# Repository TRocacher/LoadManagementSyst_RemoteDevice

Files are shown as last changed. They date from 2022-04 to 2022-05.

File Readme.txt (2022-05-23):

Branche DevRTC_StdBy_LL

-> Le développement HAL standby et RTC est un échec, le processeur est bricked car endormi à jamais...
nRST et VCC sont en CC sérieux. Voir de plus près.
-> Jusque là le code est vite lourd, 40% facile sans avoir trop rien fait...

Dans cette branche, on essaie de voir la conception en LL pour diminuer le code

Le répertoire de travail est /ExploreCodeStdby/MyNucleoL476_StdByPower

On crée un répertoire à partir de cube, en conception LL.
On va chercher l'exemple LL :
C:\Users\trocache\STM32Cube\Repository\STM32Cube_FW_L4_V1.17.2\Projects\NUCLEO-L476RG\Examples_LL\PWR\PWR_EnterStandbyMode

On récupère les 3 src et les 3 inc, que l'on copie dans le projet juste créé (remplacement de ceux créés par cube).
Compilation OK
SRC :
main.c 
stm32l4xx_it.c
system_stm32l4xx.c (est le même)

INC
main.h
stm32_assert.h
stm32l4xx_it.h

OBJ 1 : on fait idem mais périodique avec le wakeup timer.
OBJ 2 : faire tourner l'I2C en LL.

****************************
50abc65 
OBJ 1 en cours, bac à sable ajouté pour récupérer des codes générés automatiquement Cube.
/MyNucleoL476_StdByPower modifié, inspiré de RTC_ExitStandbyWithWakeUpTimer
A faire : Bien lire et faire une synthèse sur wakeup RTC Standby

****************************
349ff09
/ExploreCodeStdby / BacASable_LLFromCube
				  / MyNucleoL476_StdByPower
Programme opérationnel en standby mode !
		* PWR reset : LED s'allume 5s
		* nRST : LED s'allume 2s
		* standby wake up : LED s'allume 200ms

****************************
35642cd		
/ExploreCodeStdby / Remote_L041_StdByPower

Même programme sur 32L041F6P7
Programme opérationnel en standby mode !
		* PWR reset : PA1 (LEDIR) on 6s
		* nRST : PA1 (LEDIR) on  3s
		* standby wake up : PA1 (LEDIR) on  1s
		
Le tout sur le proto n°1 fait pas José.

****************************
2902111    
/ExploreCodeStdby / Remote_L041_StdByPower

Le programme fais une émission en boucle UART via FSK. Fonctionne à 38400 Bds, test en réception avec la carte tecom 103 de 4IS.
OK.
A faire réception.

62a0048 
/ExploreCodeStdby / Remote_L041_StdByPower
Pgm en IT à 9600 Bds, émetteur = RT606 et PC via XCTU. 
Voir main.c pour l'explication fin.
A ce stade, RxCmde, TxCmde, CD, Tx, Rx testés.

****************************	
b0ee319 
/ExploreCodeStdby / Remote_L041_StdByPower
Validation User BP en IT front descendant.

****************************
Après b0ee319 
ATTENTION CHANGEMENT REP ICI : /ExploreCodeStdby / BacASable_L041
Validation ADC mais soucis sur l'alimentation. Parasite important rayonné et conduit (20mV 100k à 30k)
qui parasite complètement l'ADC...

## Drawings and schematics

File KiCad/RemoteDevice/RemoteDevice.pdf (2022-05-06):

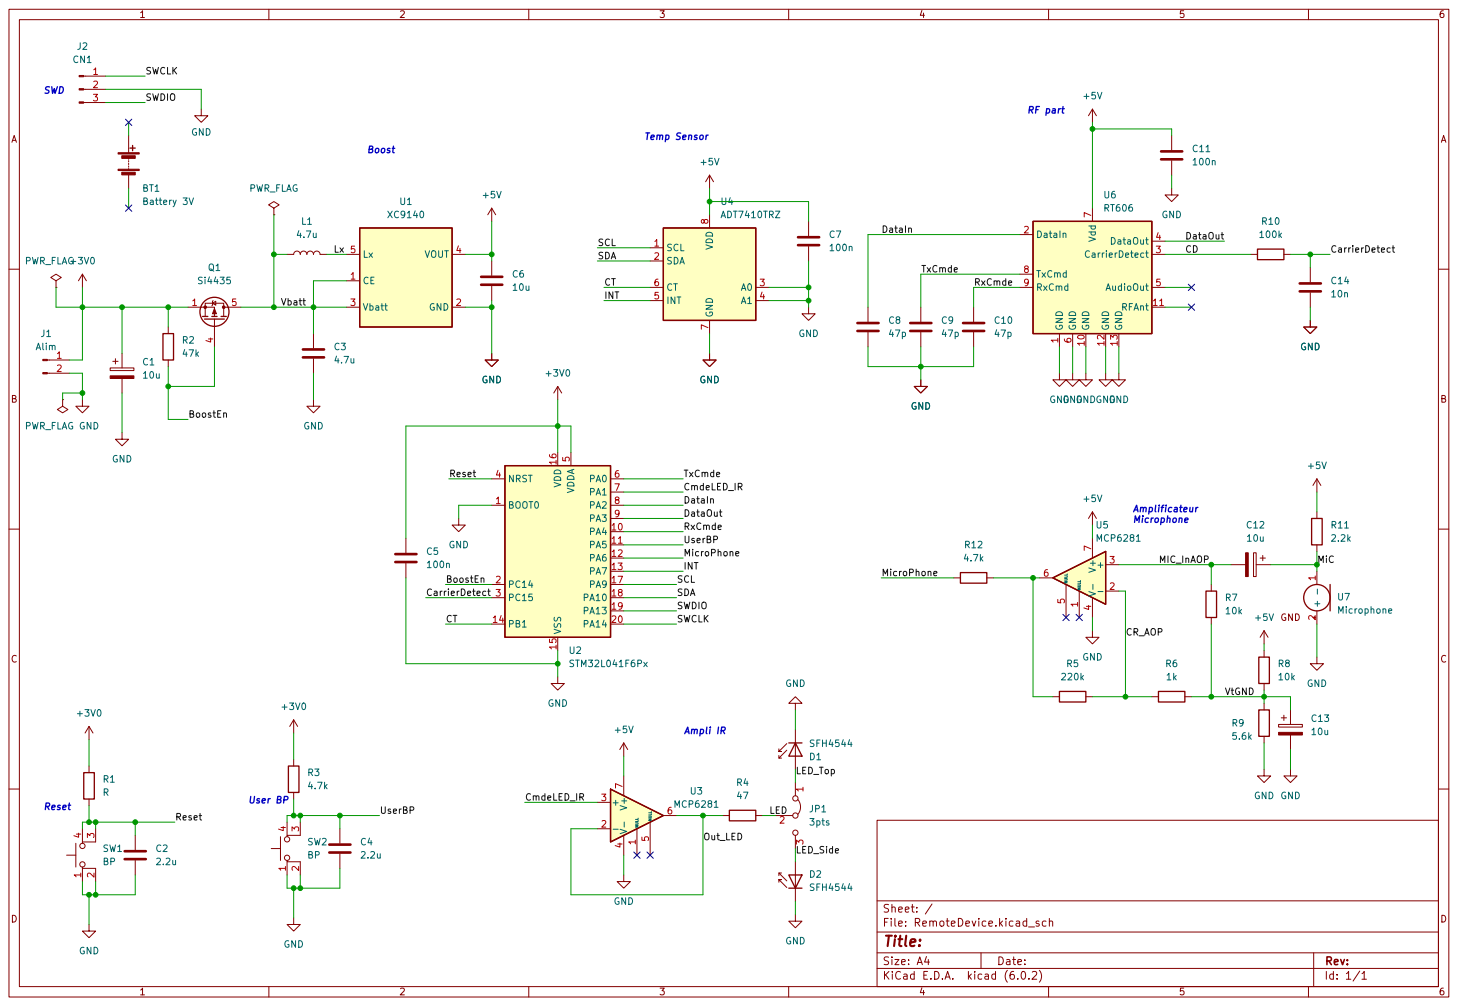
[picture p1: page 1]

1 GND 10 RFAnt 11 GND 12 GND 13 DataIn 2 CarrierDetect 3 DataOut 4 AudioOut 5 GND

File: RemoteDevice.kicad_sch Sheet: / GND

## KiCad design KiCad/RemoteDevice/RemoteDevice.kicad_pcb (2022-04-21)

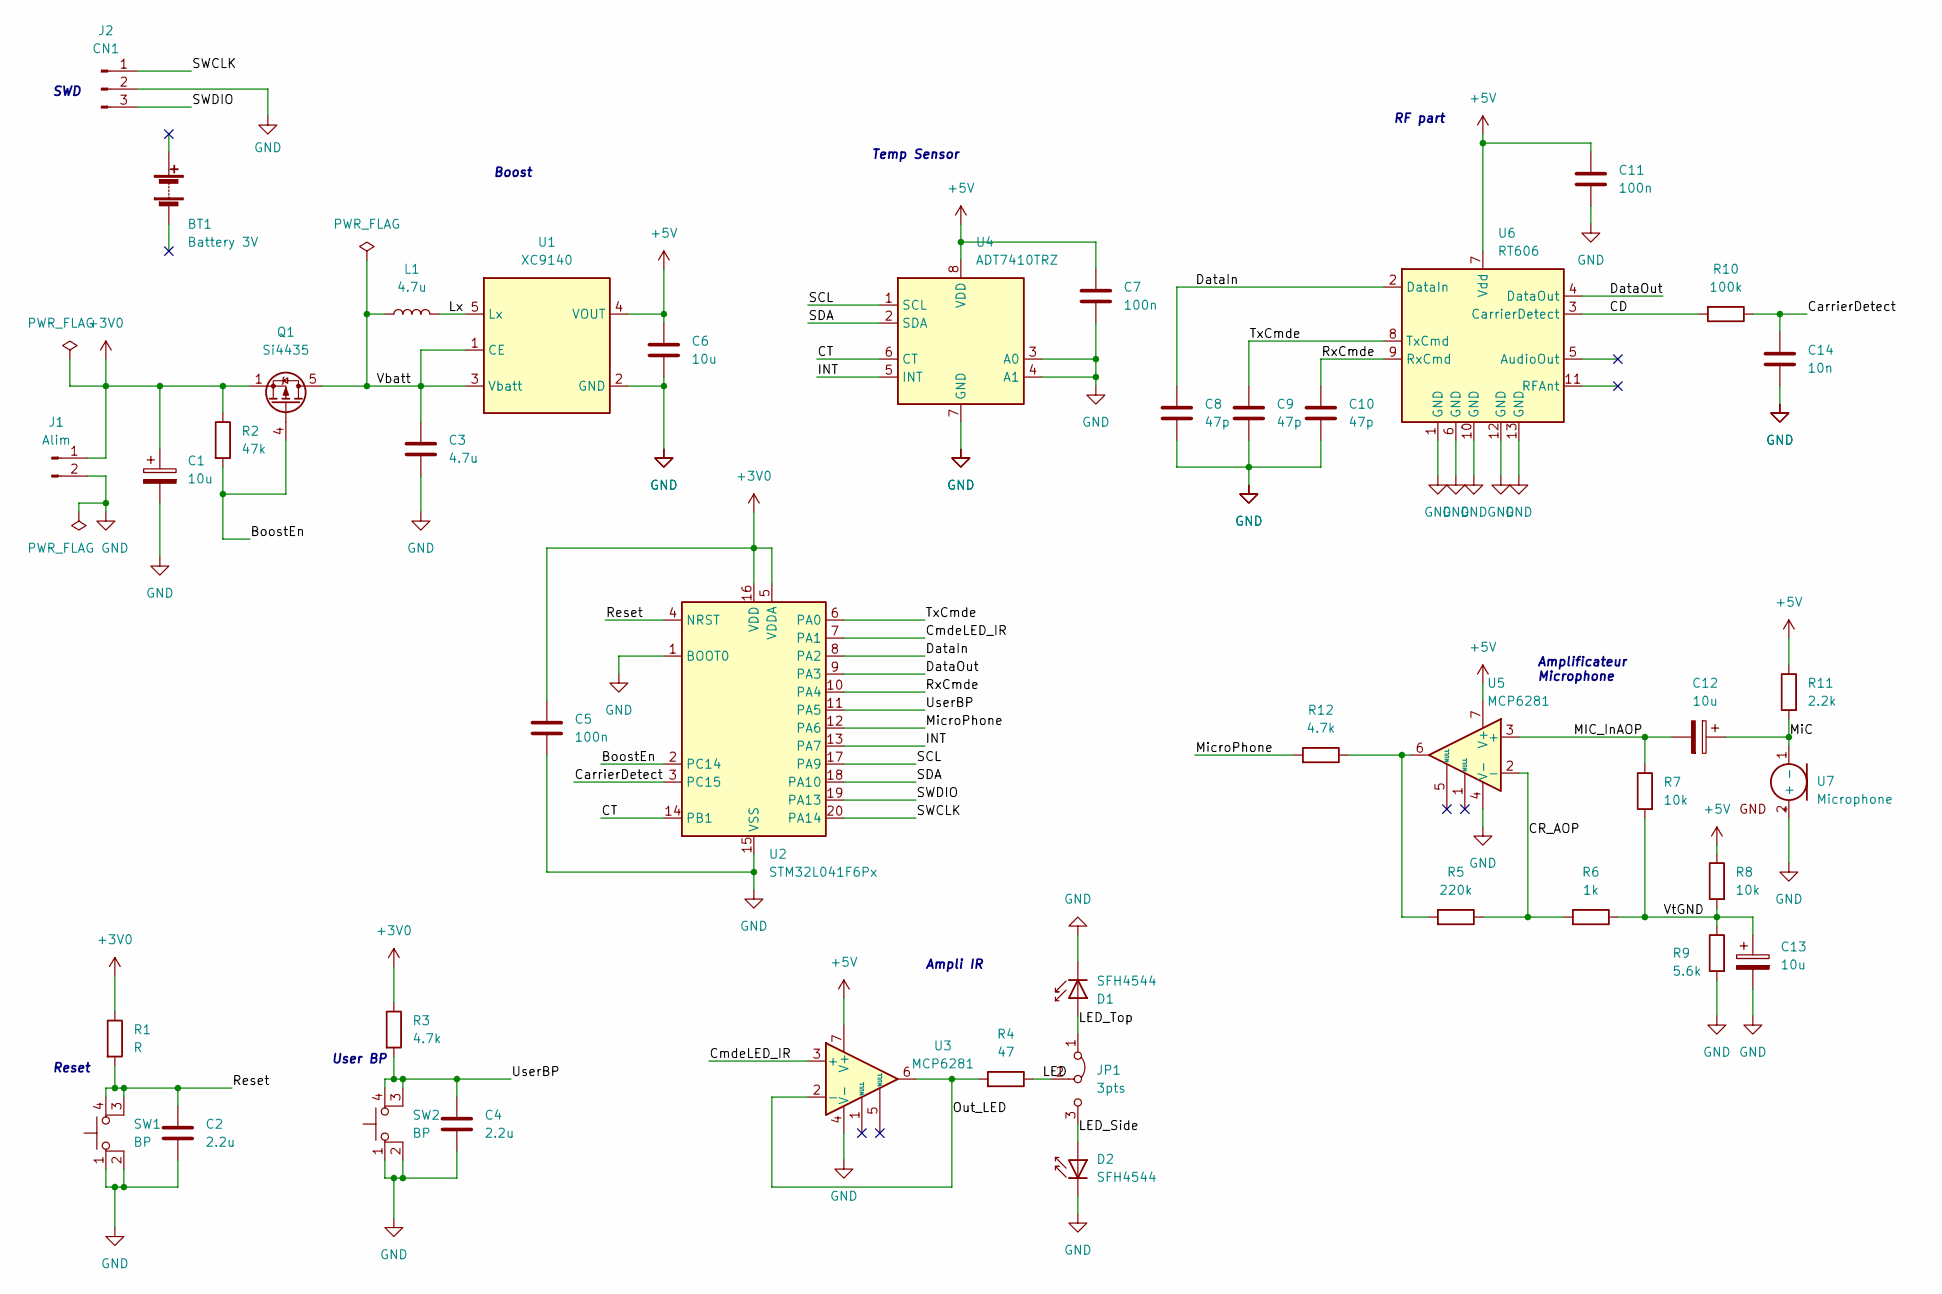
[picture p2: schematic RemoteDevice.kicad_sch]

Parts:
BT1: Battery 3V; BatteryHolder_Keystone_2468_2xAAA
C1, C12, C13: 10u; CP_EIA-7132-20_AVX-U
C2, C4: 2.2u; C_1812_4532Metric
C3: 4.7u; C_1812_4532Metric
C5, C7, C11: 100n; C_1206_3216Metric
C6: 10u; C_1812_4532Metric
C8, C9, C10: 47p; C_0805_2012Metric
C14: 10n; C_1206_3216Metric
D1, D2: SFH4544; LED_D5.0mm_IRGrey
J1: Alim; PinHeader2pts
J2: CN1; PinHeader3pts
JP1: 3pts; PinHeader3pts
L1: 4.7u; L_Abracon_ASPI-3012S
Q1: Si4435; PowerPAK_SO-8_Single
R1: R; R_1206_3216Metric
R2: 47k; R_1206_3216Metric
R3, R12: 4.7k; R_1206_3216Metric
R4: 47; R_1206_3216Metric
R5: 220k; R_1206_3216Metric
R6: 1k; R_1206_3216Metric
R7, R8: 10k; R_1206_3216Metric
R9: 5.6k; R_1206_3216Metric
R10: 100k; R_1206_3216Metric
R11: 2.2k; R_1206_3216Metric
SW1, SW2: BP; SW
U1: XC9140; SOT-23-5
U2: STM32L041F6Px; TSSOP-20_4.4x6.5mm_P0.65mm
U3, U5: MCP6281; SOIC-8_3.9x4.9mm_P1.27mm
U4: ADT7410TRZ; SOP-8_3.9x4.9mm_P1.27mm
U6: RT606
U7: Microphone

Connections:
+3V0: C1.1, C5.1, J1.1, Q1.1 (S), Q1.2 (S), Q1.3 (S), R1.1, R2.1, R3.1, U2.5 (VDDA), U2.16 (VDD)
+5V: C6.1, C7.1, C11.1, R8.1, R11.1, U1.4 (VOUT), U3.7 (V+), U4.8 (VDD), U5.7 (V+), U6.7 (Vdd)
/BoostEn: Q1.4 (G), R2.2, U2.2 (PC14)
/CD: R10.2, U6.3 (CarrierDetect)
/CR_AOP: R5.1, R6.2, U5.2 (-)
/CT: U2.14 (PB1), U4.6 (CT)
/CarrierDetect: C14.1, R10.1, U2.3 (PC15)
/CmdeLED_IR: U2.7 (PA1), U3.3 (+)
/DataIn: C8.1, U2.8 (PA2), U6.2 (DataIn)
/DataOut: U2.9 (PA3), U6.4 (DataOut)
/INT: U2.13 (PA7), U4.5 (INT)
/LED: JP1.2 (C), R4.1
/LED_Side: D2.2 (A), JP1.3 (B)
/LED_Top: D1.2 (A), JP1.1 (A)
/Lx: L1.1, U1.5 (Lx)
/MIC_InAOP: C12.2, R7.1, U5.3 (+)
/MiC: C12.1, R11.2, U7.1 (-)
/MicroPhone: R12.2, U2.12 (PA6)
/Out_LED: R4.2, U3.2 (-), U3.6
/Reset: C2.1, R1.2, SW1.3, SW1.4, U2.4 (NRST)
/RxCmde: C10.1, U2.10 (PA4), U6.9 (RxCmd)
/SCL: U2.17 (PA9), U4.1 (SCL)
/SDA: U2.18 (PA10), U4.2 (SDA)
/SWCLK: J2.1, U2.20 (PA14)
/SWDIO: J2.3, U2.19 (PA13)
/TxCmde: C9.1, U2.6 (PA0), U6.8 (TxCmd)
/UserBP: C4.1, R3.2, SW2.3, SW2.4, U2.11 (PA5)
/Vbatt: C3.1, L1.2, Q1.5 (D), U1.1 (CE), U1.3 (Vbatt)
/VtGND: C13.1, R6.1, R7.2, R8.2, R9.1
GND: C1.2, C2.2, C3.2, C4.2, C5.2, C6.2, C7.2, C8.2, C9.2, C10.2, C11.2, C13.2, C14.2, D1.1 (K), D2.1 (K), J1.2, J2.2, R9.2, SW1.1, SW1.2, SW2.1, SW2.2, U1.2 (GND), U2.1 (BOOT0), U2.15 (VSS), U3.4 (V-), U4.3 (A0), U4.4 (A1), U4.7 (GND), U5.4 (V-), U6.1 (GND), U6.6 (GND), U6.10 (GND), U6.12 (GND), U6.13 (GND), U7.2 (+)
unnamed: R5.2, R12.1, U5.6

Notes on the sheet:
Ampli IR
Boost
Reset
RF part
Amplificateur Microphone
Temp Sensor
User BP
SWD

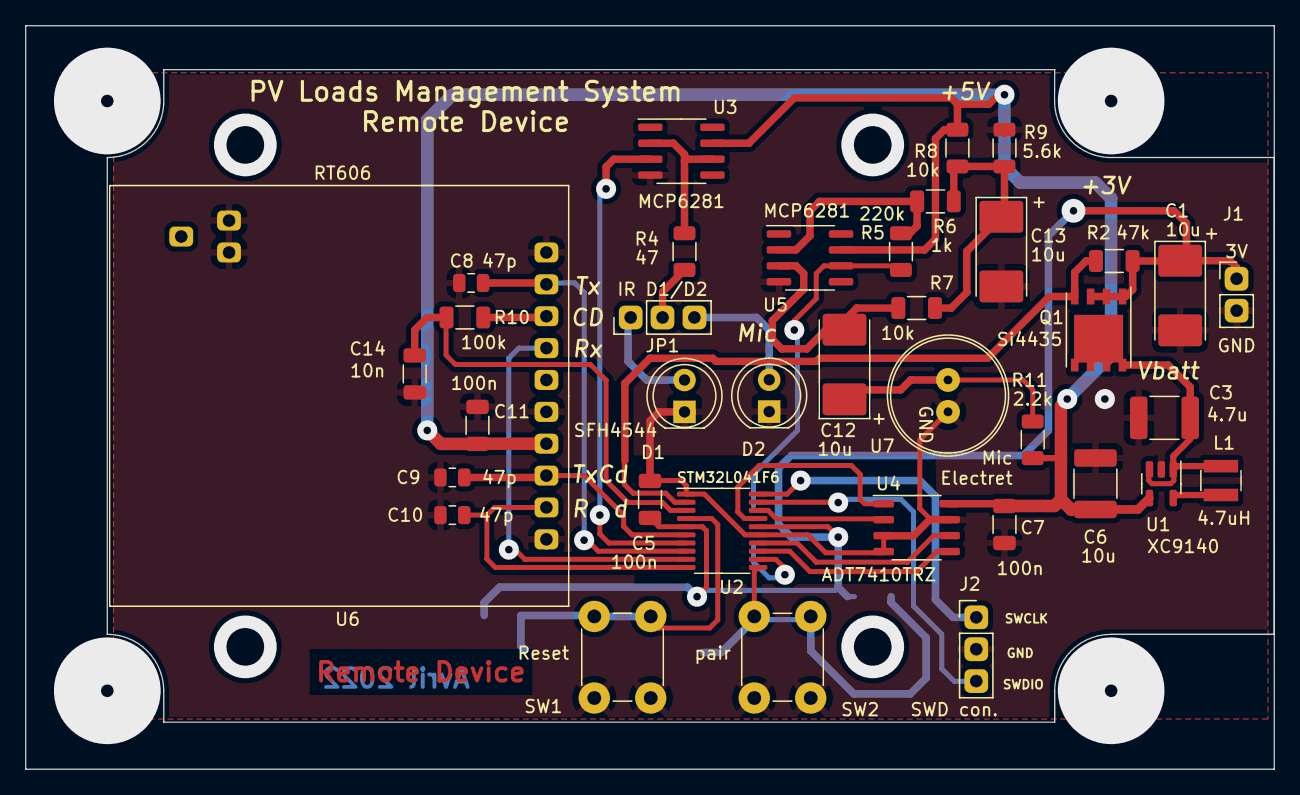
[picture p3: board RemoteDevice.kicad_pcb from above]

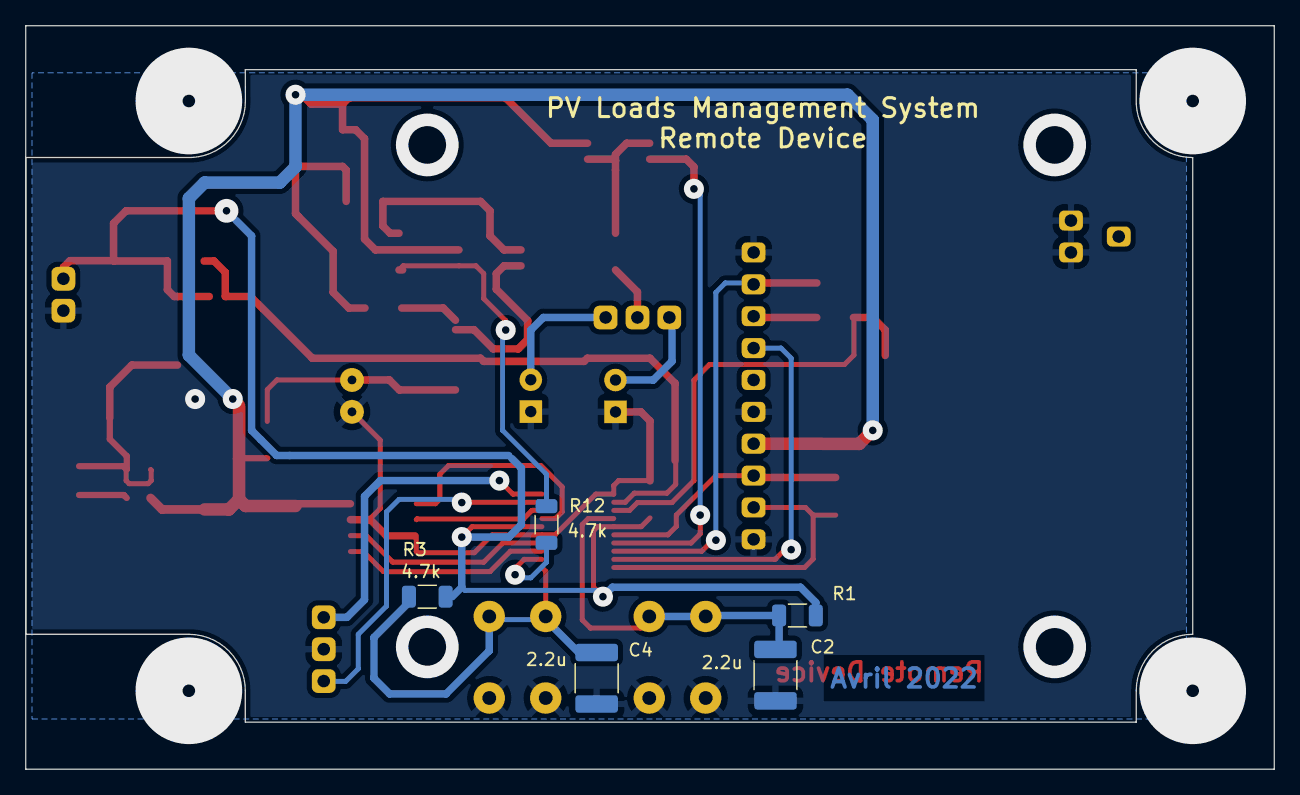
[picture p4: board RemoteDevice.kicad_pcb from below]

Board: 2 copper layers, 99.5 x 59.2 mm, 42 parts (5 on the bottom side), 31 nets.

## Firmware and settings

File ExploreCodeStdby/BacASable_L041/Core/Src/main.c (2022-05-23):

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
/* Includes ------------------------------------------------------------------*/
#include "main.h"


/* USER CODE BEGIN PV */
ErrorStatus MyErr;
/* USER CODE END PV */

void SystemClock_Config(void);
static void MX_GPIO_Init(void);
static void MX_ADC_Init(void);
static void MX_TIM22_Init(void);
/* USER CODE BEGIN PFP */

short int Tab_DMA[64];

/* USER CODE END PFP */

/**
  * @brief  The application entry point.
  * @retval int
  */
int main(void)
{
  /* MCU Configuration--------------------------------------------------------*/

  /* Reset of all peripherals, Initializes the Flash interface and the Systick. */

  LL_APB2_GRP1_EnableClock(LL_APB2_GRP1_PERIPH_SYSCFG);
  LL_APB1_GRP1_EnableClock(LL_APB1_GRP1_PERIPH_PWR);

  /* System interrupt init*/

  /* Configure the system clock */
  SystemClock_Config();

  /* Initialize all configured peripherals */
  MX_GPIO_Init();
  MX_ADC_Init();
  MX_TIM22_Init();
  /* USER CODE BEGIN 2 */

  // config EnBoost et config LED IR pour vérifier ADC trigg

  /**/
  /* GPIO Ports Clock Enable */
  LL_IOP_GRP1_EnableClock(LL_IOP_GRP1_PERIPH_GPIOC);
  LL_IOP_GRP1_EnableClock(LL_IOP_GRP1_PERIPH_GPIOA);

  LL_GPIO_InitTypeDef GPIO_InitStruct = {0};
  GPIO_InitStruct.Pin = nBoost_En_Pin;
  GPIO_InitStruct.Mode = LL_GPIO_MODE_OUTPUT;
  GPIO_InitStruct.Speed = LL_GPIO_SPEED_FREQ_LOW;
  GPIO_InitStruct.OutputType = LL_GPIO_OUTPUT_PUSHPULL;
  GPIO_InitStruct.Pull = LL_GPIO_PULL_NO;
  LL_GPIO_Init(nBoost_En_GPIO_Port, &GPIO_InitStruct);
  //Enable boost
  LL_GPIO_ResetOutputPin(nBoost_En_GPIO_Port, nBoost_En_Pin);

   // Tx cmde = 1 pour lisser le 5V ..
   /**/
   GPIO_InitStruct.Pin = TxCmde_Pin;
   GPIO_InitStruct.Mode = LL_GPIO_MODE_OUTPUT;
   GPIO_InitStruct.Speed = LL_GPIO_SPEED_FREQ_LOW;
   GPIO_InitStruct.OutputType = LL_GPIO_OUTPUT_PUSHPULL;
   GPIO_InitStruct.Pull = LL_GPIO_PULL_NO;
   LL_GPIO_Init(TxCmde_GPIO_Port, &GPIO_InitStruct);
   LL_GPIO_SetOutputPin(TxCmde_GPIO_Port, TxCmde_Pin);

   /**/
   GPIO_InitStruct.Pin = LED_IR_Pin;
   GPIO_InitStruct.Mode = LL_GPIO_MODE_OUTPUT;
   GPIO_InitStruct.Speed = LL_GPIO_SPEED_FREQ_LOW;
   GPIO_InitStruct.OutputType = LL_GPIO_OUTPUT_PUSHPULL;
   GPIO_InitStruct.Pull = LL_GPIO_PULL_NO;
   LL_GPIO_Init(LED_IR_GPIO_Port, &GPIO_InitStruct);


/*
  // Fin configuration DMA (adresse origin, dest)
  LL_DMA_SetM2MSrcAddress(DMA1, LL_DMA_CHANNEL_1, ADC_BASE+0x40);
  LL_DMA_SetM2MDstAddress(DMA1, LL_DMA_CHANNEL_1, (uint32_t)Tab_DMA);
  // fixer CNT à 64 pour lancer une première fois
  LL_DMA_SetDataLength(DMA1, LL_DMA_CHANNEL_1, 64);
  // DMA enable
  LL_DMA_EnableChannel(DMA1, LL_DMA_CHANNEL_1);
*/

   // validation IT locale
   LL_ADC_EnableIT_EOC(ADC1);
   // validation ADC
  LL_ADC_Enable(ADC1);
  // start ADC
  LL_ADC_REG_StartConversion(ADC1);

  //Lancement Timer 2
  LL_TIM_EnableCounter(TIM22);




  /* USER CODE END 2 */

  /* Infinite loop */
  /* USER CODE BEGIN WHILE */
  while (1)
  {
    /* USER CODE END WHILE */

    /* USER CODE BEGIN 3 */
  }
  /* USER CODE END 3 */
}

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


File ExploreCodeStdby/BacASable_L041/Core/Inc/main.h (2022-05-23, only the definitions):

#define nBoost_En_Pin LL_GPIO_PIN_14
#define nBoost_En_GPIO_Port GPIOC
#define TxCmde_Pin LL_GPIO_PIN_0
#define TxCmde_GPIO_Port GPIOA
#define LED_IR_Pin LL_GPIO_PIN_1
#define LED_IR_GPIO_Port GPIOA
#define NVIC_PRIORITYGROUP_0         ((uint32_t)0x00000007) /*!< 0 bit  for pre-emption priority,
#define NVIC_PRIORITYGROUP_1         ((uint32_t)0x00000006) /*!< 1 bit  for pre-emption priority,
#define NVIC_PRIORITYGROUP_2         ((uint32_t)0x00000005) /*!< 2 bits for pre-emption priority,
#define NVIC_PRIORITYGROUP_3         ((uint32_t)0x00000004) /*!< 3 bits for pre-emption priority,
#define NVIC_PRIORITYGROUP_4         ((uint32_t)0x00000003) /*!< 4 bits for pre-emption priority,

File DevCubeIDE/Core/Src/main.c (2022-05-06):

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
/* Includes ------------------------------------------------------------------*/
#include "main.h"

/* USER CODE BEGIN Includes */
#include "ADT7410_TempSensor.h"
/* USER CODE END Includes */

/* USER CODE BEGIN PTD */

// **********************************
// ** Temperature / I2C1 / ADT7140 **
// **********************************
short int Temp1_E;
short int Temp1_F;
short int Temp2_E;
short int Temp2_F;
short int Temp1,Temp2;



/* USER CODE END PTD */

ADC_HandleTypeDef hadc;

I2C_HandleTypeDef hi2c1;

RTC_HandleTypeDef hrtc;

UART_HandleTypeDef huart2;

/* USER CODE BEGIN PV */
static void SystemPower_Config(void);
/* USER CODE END PV */

void SystemClock_Config(void);
static void MX_GPIO_Init(void);
static void MX_ADC_Init(void);
static void MX_USART2_UART_Init(void);
static void MX_I2C1_Init(void);
static void MX_RTC_Init(void);
/**
  * @brief  The application entry point.
  * @retval int
  */
int main(void)
{

  // =============================================================================
  // ******************************************
  // ** POR Reset = reset Hard
  // ******************************************
  // =============================================================================

  /* MCU Configuration--------------------------------------------------------*/

  /* Reset of all peripherals, Initializes the Flash interface and the Systick. */
  HAL_Init();

  /* Configure the system clock */
  SystemClock_Config();

  /* USER CODE BEGIN SysInit */
  // pour pouvoir débugger en mode standby...
  DBGMCU->CR|=DBGMCU_CR_DBG_STANDBY;

  /* USER CODE END SysInit */

  /* Initialize all configured peripherals */
  MX_GPIO_Init();
  MX_ADC_Init();
  MX_USART2_UART_Init();
  MX_I2C1_Init();
  MX_RTC_Init();


  /* USER CODE BEGIN 2 */
   SystemPower_Config();
  /* Check and handle if the system was resumed from StandBy mode */
  if(__HAL_PWR_GET_FLAG(PWR_FLAG_SB) != RESET)
  {
    /* Clear Standby flag */
    __HAL_PWR_CLEAR_FLAG(PWR_FLAG_SB);
  }




  // ******************************************
  // ** Temperature / I2C1 / ADT7140 test OK **
  // ******************************************

  ADT7410_Init();
  Temp1=ADT7410_GetTemp_fract_9_7();
  Temp1_E =Temp1>>7;
  Temp1_F =Temp1 & 0x003F;

  // test
  HAL_GPIO_TogglePin(GPIOA, 1);

  // ******************************************
  // ** Endormissement Stanby mode			 **
  // ******************************************
  /* Clear the WAKEUPTIMER interrupt pending bit */
  //__HAL_RTC_WAKEUPTIMER_CLEAR_FLAG(hrtc, RTC_FLAG_WUTF);
  // clear global
  __HAL_PWR_CLEAR_FLAG(PWR_FLAG_WU);
  //HAL_PWR_EnterSTANDBYMode();

  /* USER CODE END 2 */

  /* Infinite loop */
  /* USER CODE BEGIN WHILE */
  while (1)
  {

    /* USER CODE END WHILE */

    /* USER CODE BEGIN 3 */
  }
  /* USER CODE END 3 */
}

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
/* USER CODE BEGIN 4 */
static void SystemPower_Config(void)
{
  /* Enable Power Control clock */
  __HAL_RCC_PWR_CLK_ENABLE();

  /* Enable Ultra low power mode */
  HAL_PWREx_EnableUltraLowPower();

  /* Enable the fast wake up from Ultra low power mode */
  HAL_PWREx_EnableFastWakeUp();
}
/* USER CODE END 4 */
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


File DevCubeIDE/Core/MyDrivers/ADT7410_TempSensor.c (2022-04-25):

/*
 * ADT7410_TempSensor.c
 *
 *  Created on: 21 avr. 2022
 *      Author: trocache
 */



#include "ADT7410_TempSensor.h"




static uint8_t data[4];

// on shot mode, 16bits data format
void ADT7410_Init(void)
{
	uint8_t ConfRegVal;
	ConfRegVal=ConfReg_Reso_16;
	ConfRegVal|=ConfReg_Mode_Shutdown;

	data[0]=ConfRegAdr;
	data[1]=ConfRegVal;

	HAL_I2C_Master_Transmit(&hi2c1, ADT7410_Slave8bitsAdr, data,2, HAL_MAX_DELAY);
}


short int ADT7410_GetTemp_fract_9_7(void)
{
	uint8_t ConfRegVal;
	short int ReturnValue;

	// Lancement one shot
	ConfRegVal=ConfReg_Reso_16;
	ConfRegVal|=ConfReg_Mode_OneShot;
	data[0]=ConfRegAdr;
	data[1]=ConfRegVal;
	HAL_I2C_Master_Transmit(&hi2c1, ADT7410_Slave8bitsAdr, data,2, HAL_MAX_DELAY);


	// Wait at least 240ms
	HAL_Delay(250);


	// Read temperature
	HAL_I2C_Mem_Read(&hi2c1, ADT7410_Slave8bitsAdr, TempHighAdr,1,data,2,HAL_MAX_DELAY);
	ReturnValue=(data[0]<<8)+data[1];

	return ReturnValue;

	}

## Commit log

2022-04-21 Kicad correspond à le varsion GEI du 21 04 2022. Cube IDE démarré avec la cible STM32L041F6. I2C demarré, Cube Mx OK IO sauf TIM2 Ch2 (IR)
    [RemoteDevice.kicad_pcb, RemoteDevice.kicad_sch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]
2022-04-25 I2C Temperature OK sur Remote Device. Rem : code très lourd déjà plus de 50% !
2022-04-26 RTC HAL débuté. La RTC tourne à 1 Hz, le calendar évolue bien. La LSI est assez précise. La lecture HAL merde. Création Aide RTC txt.
2022-05-06 Migration example ST Pwr Stdby vers rep local, developpement LL. Code qui tourne sur nucléo 476RG conformément à l'exemple
    [RemoteDevCode Debug.cfg]
2022-05-07 avancement du programme : à terminer pour un réveil toutes les 5 secondes.
2022-05-15 standby OK sur proto Remote Device L041. Test sur LED IR, PA1. Voir readme pour les détails
2022-05-22 Validation RT606 en réception, 9600 Bds via PC et XCTU. Vérif ligne CD via scope
    [StdByPower_L041 Debug.cfg]
2022-05-23 Validation ADC (trigger TIM22, DMA loupée avec Cube, possible qu'il manque juste un start DMA... Soucis avec bruit du boost

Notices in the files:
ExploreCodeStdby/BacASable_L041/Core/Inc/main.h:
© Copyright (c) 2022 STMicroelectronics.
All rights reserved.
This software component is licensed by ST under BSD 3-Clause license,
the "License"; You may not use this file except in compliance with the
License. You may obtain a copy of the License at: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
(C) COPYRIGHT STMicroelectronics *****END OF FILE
